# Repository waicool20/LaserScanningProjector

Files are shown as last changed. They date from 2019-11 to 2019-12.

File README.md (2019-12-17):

# Laser Scanning Projector

Use a scanning laser to draw images onto a surface!

## Project Structure

- `Hardware`: Contains PCB schematics and STM32CubeMX IOC file
- `Software`: Software for the MCU
- `Software-PC`: PC-side software for streaming USB data
- `Report`: Report for submission to course

# License

Hardware: Creative Commons Attribution-ShareAlike 4.0 International

Software: MIT

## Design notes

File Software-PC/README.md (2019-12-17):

# Laser Scanning Projector - PC Companion Software

Companion software for streaming image data to the Laser Scanning Projector.

## Getting Started

These instructions will set the project up and run the application on your 
local machine. Note that currently only the Linux platform is officially tested 
and supported.

### Prerequisites

- [CMake 3.10.0+](https://cmake.org/download/)
- Any C++17-supported compiler

### Compiling and Running

Run CMake in a separate directory.
```bash
cmake -G "CodeBlocks - Unix Makefiles" ..
cmake --build . --target all
```

The application will be named as `LaserScanningProject-PC`.

## Usage

```
LaserScanningProject-PC <image_file>
```

- `<image_file>`: Path to the image file to render

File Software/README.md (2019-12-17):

# Laser Scanning Projector

## Prerequisites

You will be needing the following to compile:

- [arm-none-eabi-gcc](https://developer.arm.com/open-source/gnu-toolchain/gnu-rm)
- [CMake](https://cmake.org/)
- [GNU Make](https://www.gnu.org/software/make/)
- [Python](https://www.python.org/)

## Usage

1. Clone this repository to your local system. 

```bash
git clone https://github.com/waicool20/LaserScanningProjector.git
```

2. Initialize all the submodule dependencies.

```bash
cd LaserScanningProjector
git submodule update --init --recursive
```

3. Build LibOpenCM3.

This step is required by RTLib to recognize which targets are supported by libopencm3. Subsequent builds can skip this 
step, as building RTLib will implicitly build libopencm3.

```bash
cd Software/libopencm3
make
cd ..
```
4. Try to build the application.

```bash
# Create a new folder to house all CMake-related files.
mkdir cmake-build && cd cmake-build

# Change the -G option according to your build system, might be different for example if you were using MinGW.
cmake -DCMAKE_BUILD_TYPE=Debug -DCMAKE_TOOLCHAIN_FILE=../cmake/arm-toolchain.cmake -G "CodeBlocks - Unix Makefiles" ..

# Finally run the make command to initate the build process. This will build everything into the "cmake-build" folder.
cmake --build . --target all
```

The resulting binaries (`LaserScanningProjector.bin` and `LaserScanningProjector.elf`) will be located in the same 
directory.

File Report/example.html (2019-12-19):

## ELEC 3300 Final Project

## Title: <Laser Scanning Projector>

## Group: 26

Members Name | Ching Hang MAK | Wai Paulo Valerio WANG
Members Email | chmakac@connect.ust.hk | wpvwang@connect.ust.hk

# Project Resources

## Project Summary

## Proposal Presentation Video (https://photos.app.goo.gl/xhKpi9jK36LHvkUt7)

## Project Interim Demo Video (https://photos.app.goo.gl/K36WhH9UAJNqvfp79)

## Project Final PowerPoint Presentation

## Working Function Demo (https://photos.app.goo.gl/PB6YHP3vdHEFazZNA)

## STM32CubeMX ioc file

## Software Source Code (Mirror: GitHub (https://github.com/waicool20/LaserScanningProjector/tree/master/Software))

## GitHub (Contains source code for everything) (https://github.com/waicool20/LaserScanningProjector/)

# Photos

For more photos please check the Timeline section in 'Project Final PowerPoint Presentation'

## Front View Photo



## Top View Photo

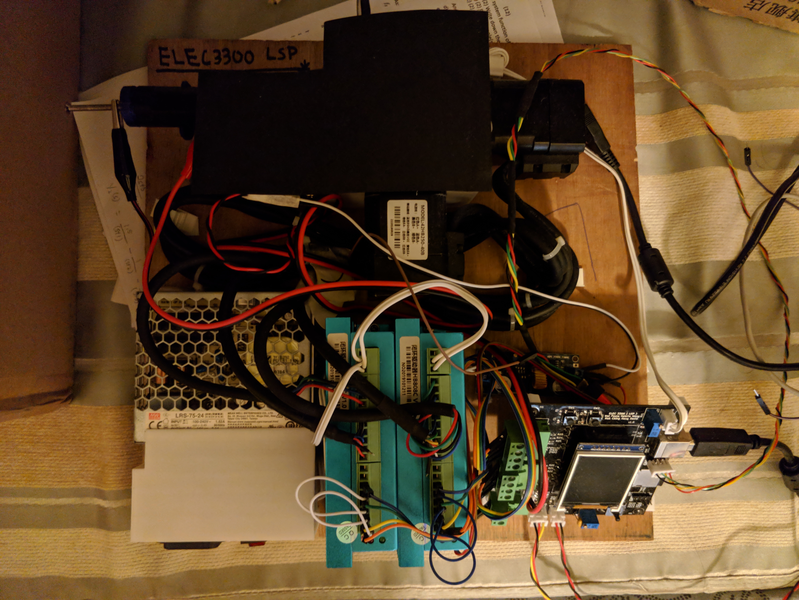
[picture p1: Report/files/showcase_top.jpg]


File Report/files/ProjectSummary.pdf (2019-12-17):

## ELEC 3300 Project Summary Sheet

This is a ONE Page Summary Sheet, Content more than 1 page will be deleted. All the fonts used in this Sheet should be in Times New Roman at 12 points

Group Number | 26
Project Title | Laser Scanning Projector
Name of Student 1 | Wai Paulo Valerio Wang
Name of Student 2 | Mak Ching Hang David

Please attach ONE photo of your project here

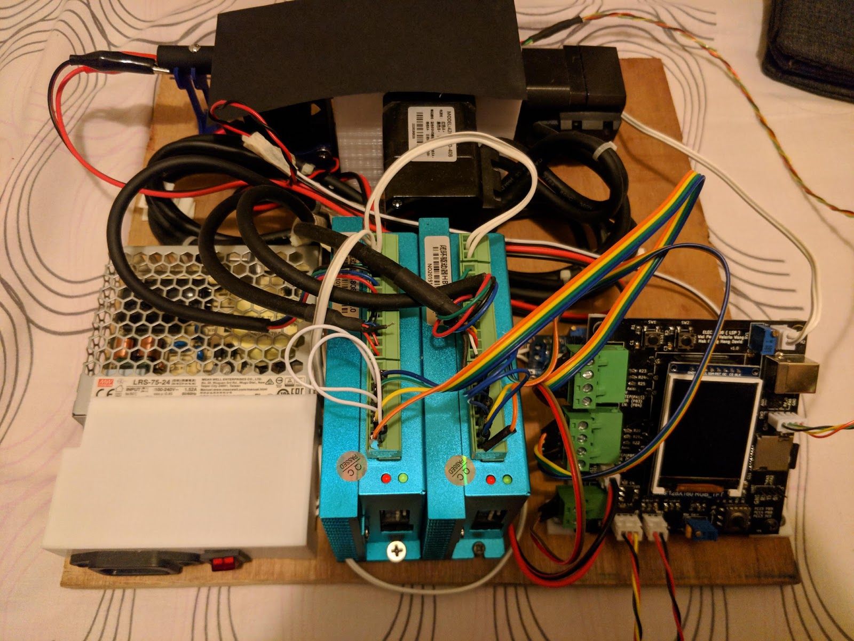
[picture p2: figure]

Please list the functions of your project in point form

- Draw image using laser, multiple data sources
- Data from memory
- Data from sd card
- Data from usb
- Data from uart
- Plot audio magnitude as y axis, audio source from mic
- Plot audio magnitude as xy axis, audio source from headphone jack
- LCD for mode selection
- Auto Homing

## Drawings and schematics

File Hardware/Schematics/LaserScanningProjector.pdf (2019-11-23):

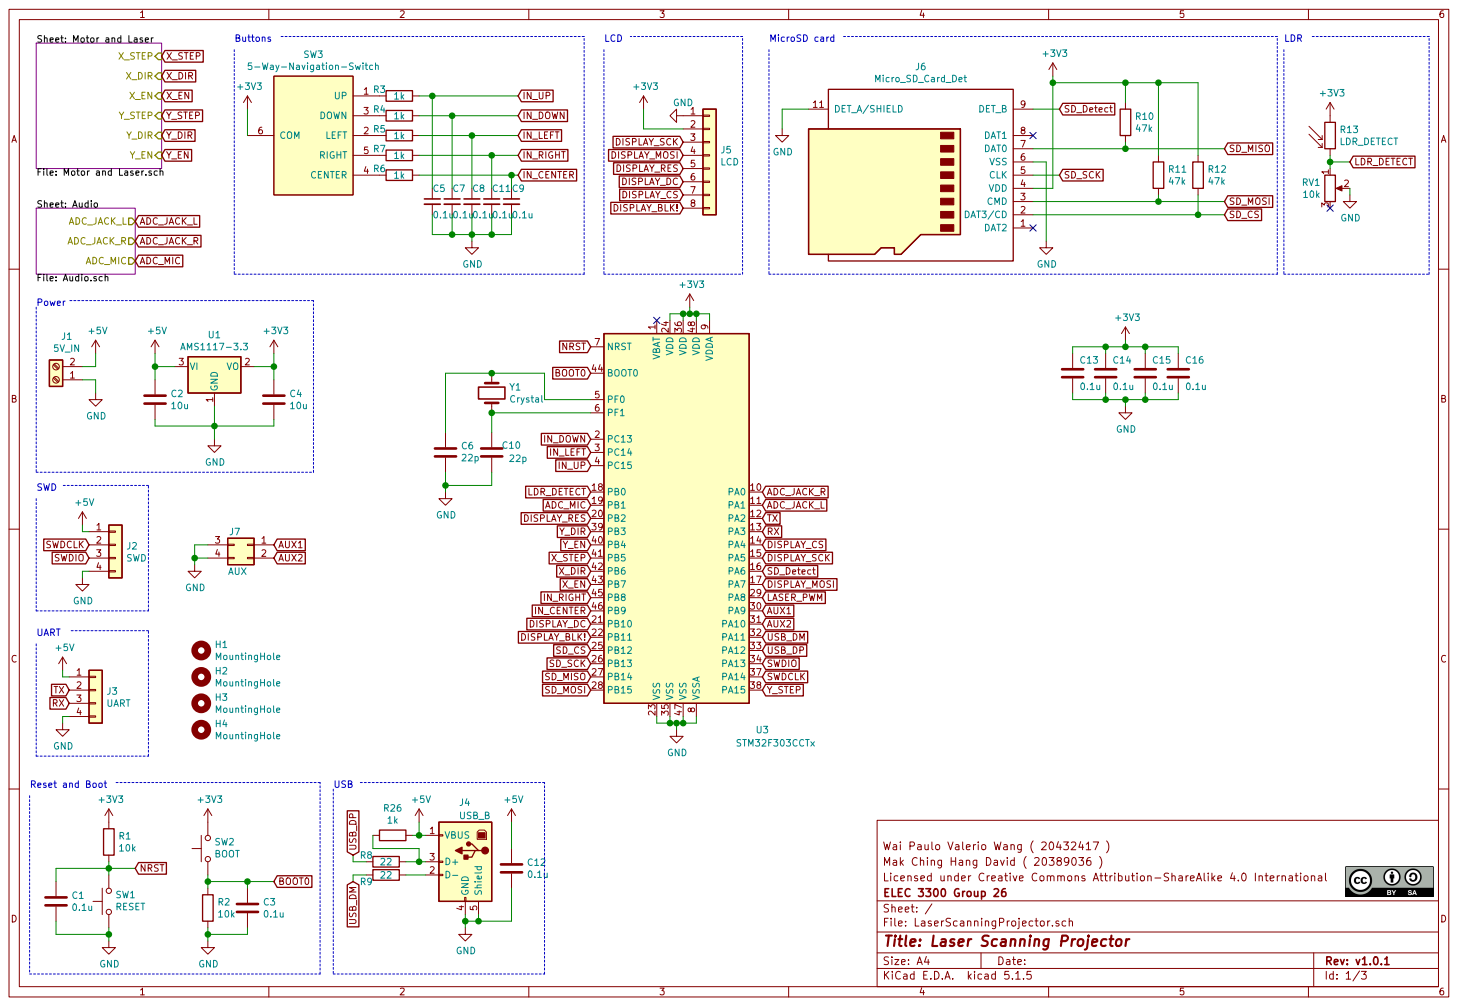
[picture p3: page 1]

Sheet: Motor and Laser File: Motor and Laser.sch X_STEP

Sheet: Audio File: Audio.sch ADC_JACK_L ADC_JACK_R

1 VDD 24 VDD 36 VDD 48 VDDA

9 VSS 23 VSS 35 VSS 47 VSSA

Wai Paulo Valerio Wang ( 20432417 )
Licensed under Creative Commons Attribution-ShareAlike 4.0 International Mak Ching Hang David ( 20389036 )

File: LaserScanningProjector.sch Sheet: / ELEC 3300 Group 26

Id: 1/3 Title: Laser Scanning Projector

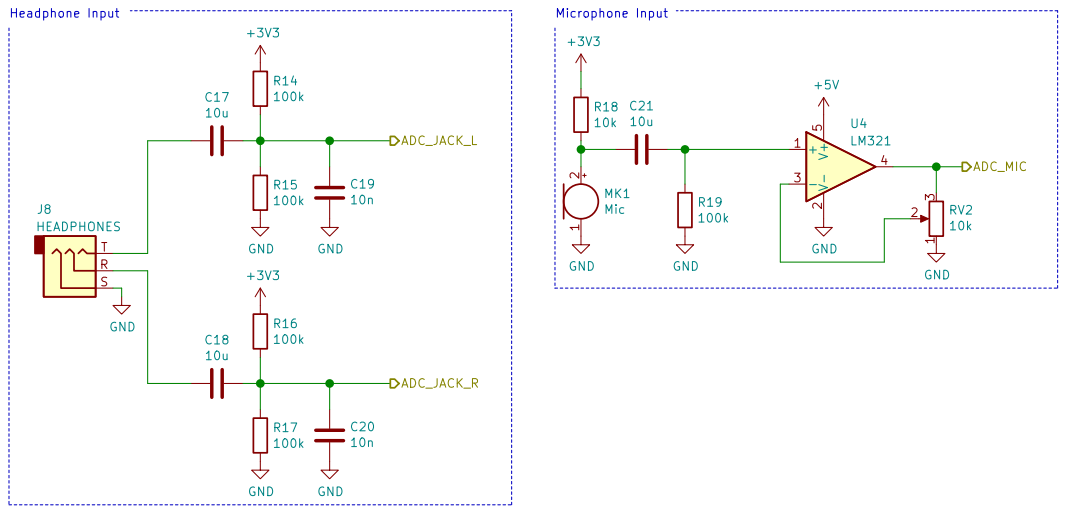
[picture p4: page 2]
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

Id: 2/3 Title: Laser Scanning Projector File: Audio.sch Sheet: /Audio/ ELEC 3300 Group 26

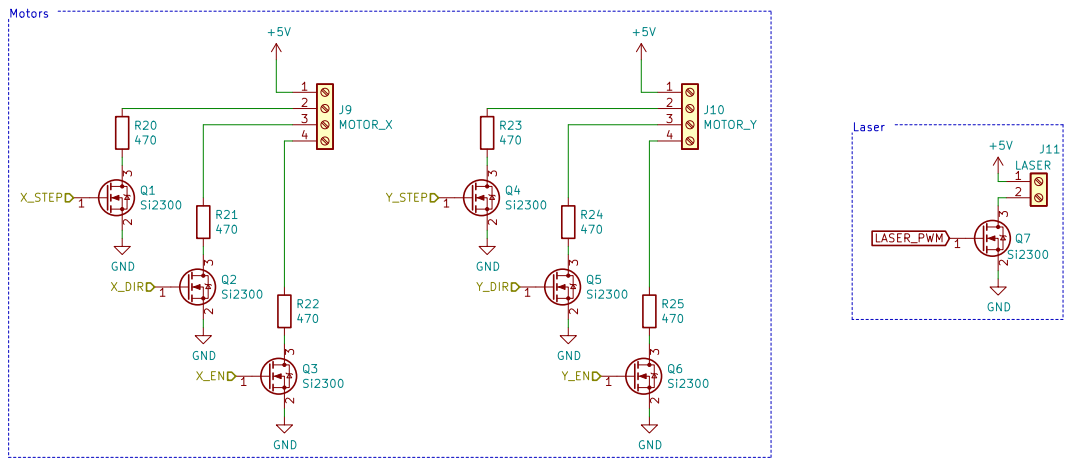
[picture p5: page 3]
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

Id: 3/3 Title: Laser Scanning Projector File: Motor and Laser.sch Sheet: /Motor and Laser/ ELEC 3300 Group 26

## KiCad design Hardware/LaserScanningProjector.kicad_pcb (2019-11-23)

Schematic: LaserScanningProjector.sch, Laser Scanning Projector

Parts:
C1, C3, C5, C7, C8, C9, C11, C12, C13, C14, C15, C16: 0.1u; C_0805_2012Metric_Pad1.15x1.40mm_HandSolder
C2, C4: 10u; C_0805_2012Metric_Pad1.15x1.40mm_HandSolder
C6, C10: 22p; C_0805_2012Metric_Pad1.15x1.40mm_HandSolder
H1, H2, H3, H4: MountingHole; MountingHole_3.2mm_M3_Pad
J1: 5V_IN; PhoenixContact_MSTBA_2,5_2-G-5,08_1x02_P5.08mm_Horizontal
J2: SWD; PinHeader_1x04_P2.54mm_Vertical
J3: UART; PinHeader_1x04_P2.54mm_Vertical
J4: USB_B
J5: LCD
J6: Micro_SD_Card_Det; Micro_SD
J7: AUX; PinHeader_2x02_P2.54mm_Vertical
R1, R2: 10k; R_0805_2012Metric_Pad1.15x1.40mm_HandSolder
R3, R4, R5, R6, R7, R26: 1k; R_0805_2012Metric_Pad1.15x1.40mm_HandSolder
R8, R9: 22; R_0805_2012Metric_Pad1.15x1.40mm_HandSolder
R10, R11, R12: 47k; R_0805_2012Metric_Pad1.15x1.40mm_HandSolder
R13: LDR_DETECT; JST_XH_B2B-XH-A_1x02_P2.50mm_Vertical
RV1: 10k; Potentiometer_Bourns_3296W_Vertical
SW1: RESET; SW_SPST_PTS645
SW2: BOOT; SW_SPST_PTS645
SW3: 5-Way-Navigation-Switch; 5-Way-Nagivation-Switch
U1: AMS1117-3.3; SOT-223-3_TabPin2
U3: STM32F303CCTx; LQFP-48_7x7mm_P0.5mm
Y1: Crystal; Crystal_HC49-4H_Vertical

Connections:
+3V3: C4.1, C13.1, C14.1, C15.1, C16.1, J5.2, J6.4 (VDD), R1.1, R10.1, R11.1, R12.1, R13.1, SW2.2, SW3.6, U1.2 (VO), U3.9 (VDDA), U3.24 (VDD), U3.36 (VDD), U3.48 (VDD); also elsewhere on the board
+5V: C2.1, C12.1, J1.2, J2.1, J3.1, J4.1 (VBUS), R26.1, U1.3 (VI); also elsewhere on the board
ADC_JACK_L: U3.11 (PA1); also elsewhere on the board
ADC_JACK_R: U3.10 (PA0); also elsewhere on the board
ADC_MIC: U3.19 (PB1); also elsewhere on the board
AUX1: J7.1, U3.30 (PA9)
AUX2: J7.2, U3.31 (PA10)
BOOT0: C3.1, R2.1, SW2.1, U3.44 (BOOT0)
DISPLAY_BLK!: J5.8, U3.22 (PB11)
DISPLAY_CS: J5.7, U3.14 (PA4)
DISPLAY_DC: J5.6, U3.21 (PB10)
DISPLAY_MOSI: J5.4, U3.17 (PA7)
DISPLAY_RES: J5.5, U3.20 (PB2)
DISPLAY_SCK: J5.3, U3.15 (PA5)
GND: C1.2, C2.2, C3.2, C4.2, C5.2, C6.1, C7.2, C8.2, C9.2, C10.1, C11.2, C12.2, C13.2, C14.2, C15.2, C16.2, J1.1, J2.4, J3.4, J4.4 (GND), J4.5 (Shield), J5.1, J6.6 (VSS), J6.11 (DET_A/SHIELD), J7.3, J7.4, R2.2, RV1.2, SW1.1, U1.1 (GND), U3.8 (VSSA), U3.23 (VSS), U3.35 (VSS), U3.47 (VSS); also elsewhere on the board
IN_CENTER: C9.1, R6.1, U3.46 (PB9)
IN_DOWN: C7.1, R4.1, U3.2 (PC13)
IN_LEFT: C8.1, R5.1, U3.3 (PC14)
IN_RIGHT: C11.1, R7.1, U3.45 (PB8)
IN_UP: C5.1, R3.1, U3.4 (PC15)
LASER_PWM: U3.29 (PA8); also elsewhere on the board
LDR_DETECT: R13.2, RV1.1, U3.18 (PB0)
NRST: C1.1, R1.2, SW1.2, U3.7 (NRST)
unnamed: C6.2, U3.5 (PF0), Y1.1
unnamed: C10.2, U3.6 (PF1), Y1.2
unnamed: J4.2 (D-), R9.1
unnamed: J4.3 (D+), R8.1, R26.2
unnamed: R3.2, SW3.1
unnamed: R4.2, SW3.3
unnamed: R5.2, SW3.2
unnamed: R6.2, SW3.4
unnamed: R7.2, SW3.5
RX: J3.3, U3.13 (PA3)
SD_CS: J6.2 (DAT3/CD), R12.2, U3.25 (PB12)
SD_Detect: J6.9 (DET_B), U3.16 (PA6)
SD_MISO: J6.7 (DAT0), R10.2, U3.27 (PB14)
SD_MOSI: J6.3 (CMD), R11.2, U3.28 (PB15)
SD_SCK: J6.5 (CLK), U3.26 (PB13)
SWDCLK: J2.2, U3.37 (PA14)
SWDIO: J2.3, U3.34 (PA13)
TX: J3.2, U3.12 (PA2)
USB_DM: R9.2, U3.32 (PA11)
USB_DP: R8.2, U3.33 (PA12)
X_DIR: U3.42 (PB6); also elsewhere on the board
X_EN: U3.43 (PB7); also elsewhere on the board
X_STEP: U3.41 (PB5); also elsewhere on the board
Y_DIR: U3.39 (PB3); also elsewhere on the board
Y_EN: U3.40 (PB4); also elsewhere on the board
Y_STEP: U3.38 (PA15); also elsewhere on the board

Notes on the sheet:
Reset and Boot
SWD
UART
USB
MicroSD card
LCD
Buttons
LDR
Power

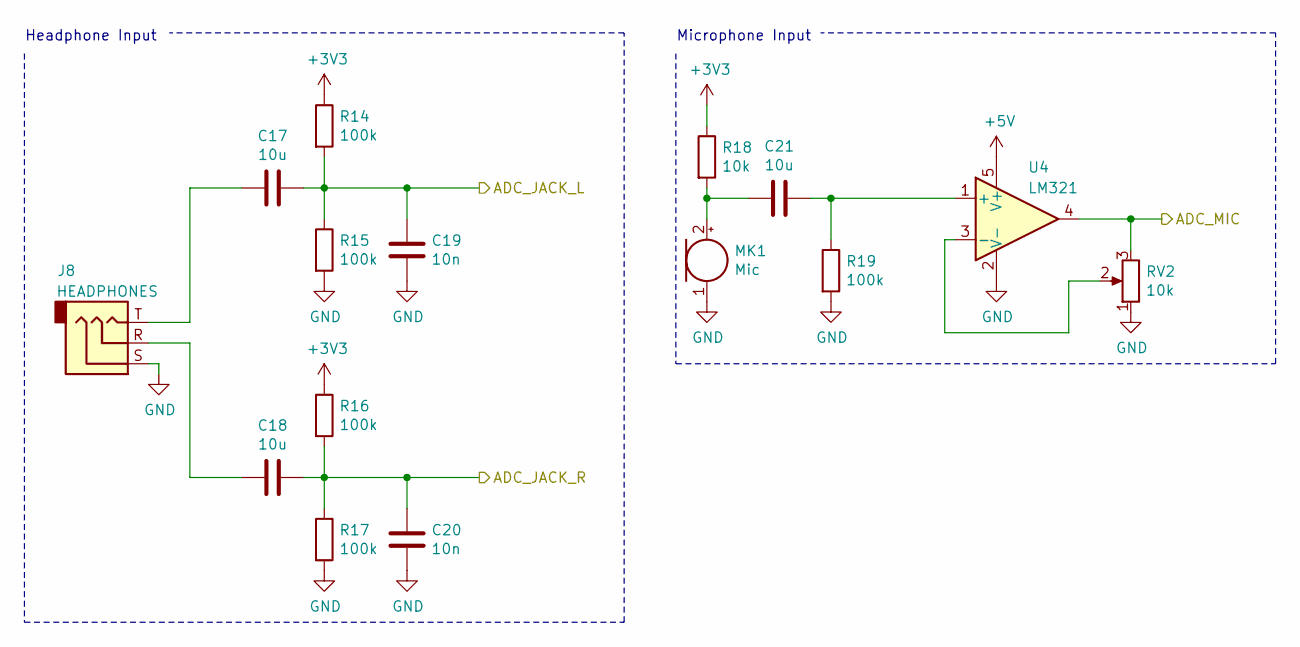
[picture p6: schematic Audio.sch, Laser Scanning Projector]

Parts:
C17, C18, C21: 10u; C_0805_2012Metric_Pad1.15x1.40mm_HandSolder
C19, C20: 10n; C_0805_2012Metric_Pad1.15x1.40mm_HandSolder
J8: HEADPHONES; JST_XH_B3B-XH-A_1x03_P2.50mm_Vertical_RST_AUDIO
MK1: Mic; JST_XH_B2B-XH-A_1x02_P2.50mm_Vertical
R14, R15, R16, R17, R19: 100k; R_0805_2012Metric_Pad1.15x1.40mm_HandSolder
R18: 10k; R_0805_2012Metric_Pad1.15x1.40mm_HandSolder
RV2: 10k; Potentiometer_Bourns_3296W_Vertical
U4: LM321; SOT-23-5

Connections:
+3V3: R14.1, R16.1, R18.1; also elsewhere on the board
+5V: U4.5 (V+); also elsewhere on the board
ADC_JACK_L: C17.1, C19.2, R14.2, R15.1; also elsewhere on the board
ADC_JACK_R: C18.1, C20.2, R16.2, R17.1; also elsewhere on the board
ADC_MIC: RV2.3, U4.4; also elsewhere on the board
GND: C19.1, C20.1, J8.S, MK1.1 (-), R15.2, R17.2, R19.2, RV2.1, U4.2 (V-); also elsewhere on the board
unnamed: C17.2, J8.T
unnamed: C18.2, J8.R
unnamed: C21.1, R19.1, U4.1 (+)
unnamed: C21.2, MK1.2 (+), R18.2
unnamed: RV2.2, U4.3 (-)

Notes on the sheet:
Headphone Input
Microphone Input

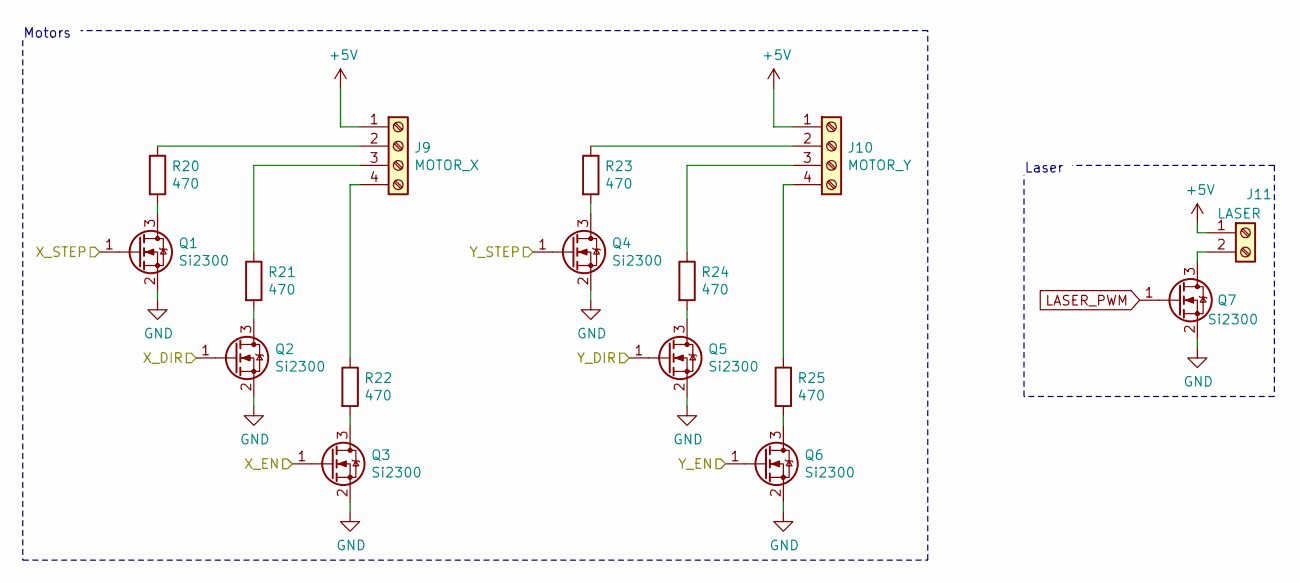
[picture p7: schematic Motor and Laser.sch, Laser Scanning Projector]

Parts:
J9: MOTOR_X; PhoenixContact_MSTBA_2,5_4-G-5,08_1x04_P5.08mm_Horizontal
J10: MOTOR_Y; PhoenixContact_MSTBA_2,5_4-G-5,08_1x04_P5.08mm_Horizontal
J11: LASER; JST_XH_B2B-XH-A_1x02_P2.50mm_Vertical
Q1, Q2, Q3, Q4, Q5, Q6, Q7: Si2300; SOT-23
R20, R21, R22, R23, R24, R25: 470; R_0805_2012Metric_Pad1.15x1.40mm_HandSolder

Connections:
+5V: J9.1, J10.1, J11.1; also elsewhere on the board
GND: Q1.2 (S), Q2.2 (S), Q3.2 (S), Q4.2 (S), Q5.2 (S), Q6.2 (S), Q7.2 (S); also elsewhere on the board
LASER_PWM: Q7.1 (G); also elsewhere on the board
unnamed: J9.2, R20.1
unnamed: J9.3, R21.1
unnamed: J9.4, R22.1
unnamed: J10.2, R23.1
unnamed: J10.3, R24.1
unnamed: J10.4, R25.1
unnamed: J11.2, Q7.3 (D)
unnamed: Q1.3 (D), R20.2
unnamed: Q2.3 (D), R21.2
unnamed: Q3.3 (D), R22.2
unnamed: Q4.3 (D), R23.2
unnamed: Q5.3 (D), R24.2
unnamed: Q6.3 (D), R25.2
X_DIR: Q2.1 (G); also elsewhere on the board
X_EN: Q3.1 (G); also elsewhere on the board
X_STEP: Q1.1 (G); also elsewhere on the board
Y_DIR: Q5.1 (G); also elsewhere on the board
Y_EN: Q6.1 (G); also elsewhere on the board
Y_STEP: Q4.1 (G); also elsewhere on the board

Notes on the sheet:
Motors
Laser

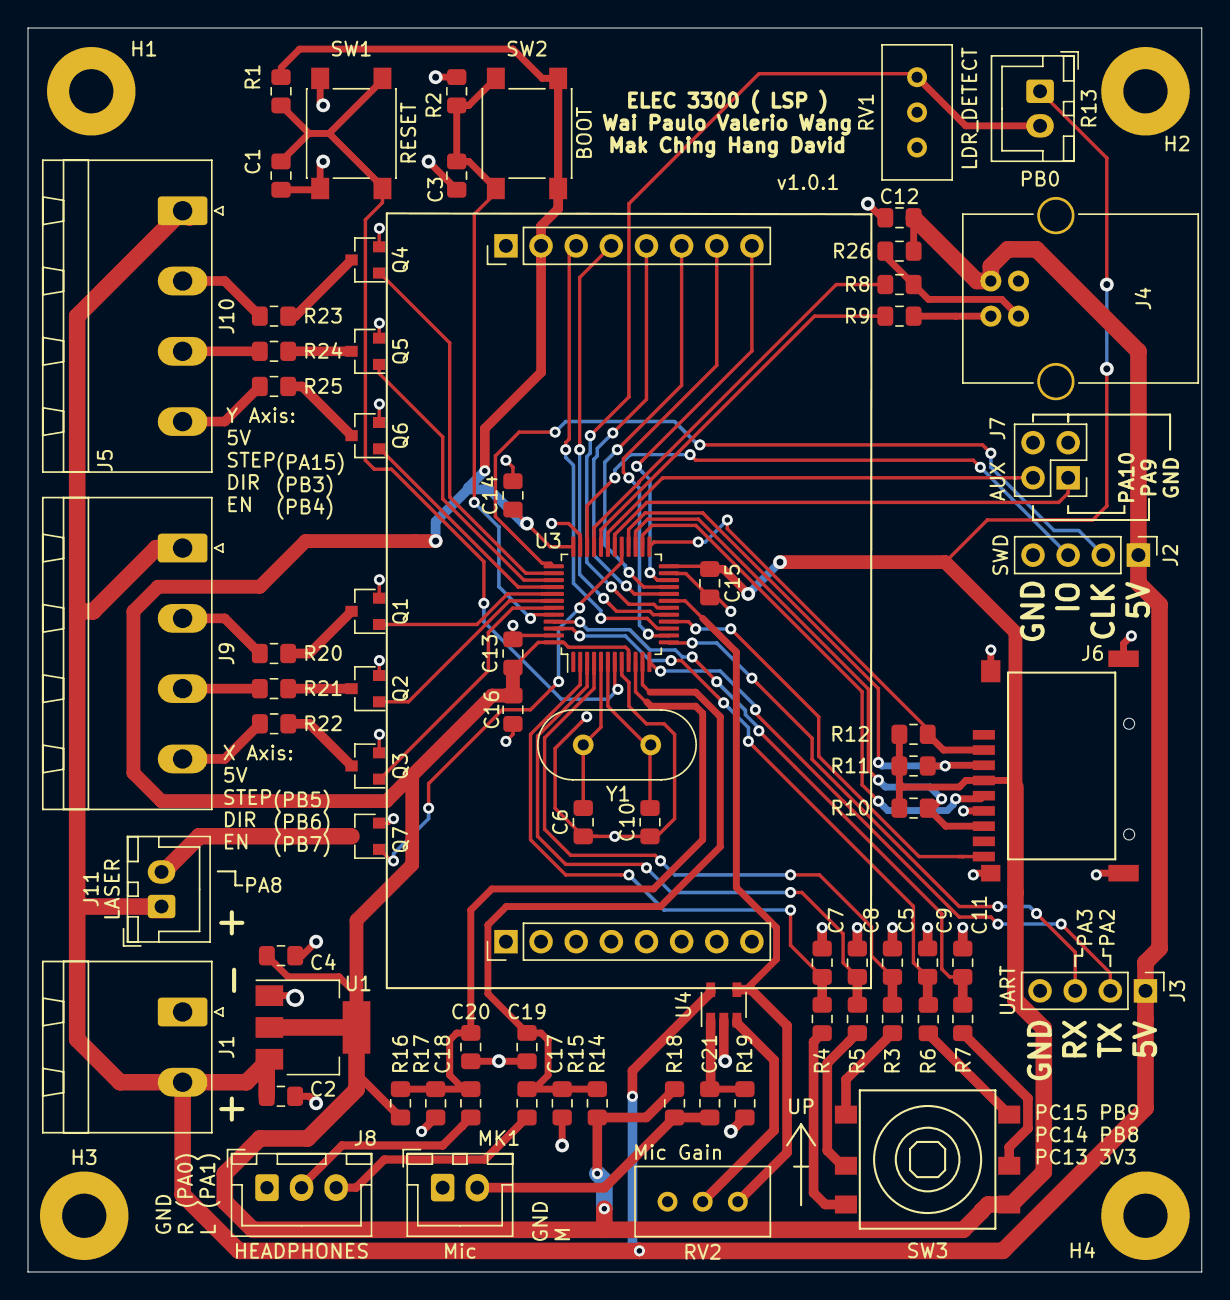
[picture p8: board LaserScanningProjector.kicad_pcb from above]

Board: 2 copper layers, 84.8 x 89.9 mm, 79 parts (0 on the bottom side), 67 nets.

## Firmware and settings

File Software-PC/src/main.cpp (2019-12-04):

#include <array>
#include <numeric>
#include <string_view>
#include <thread>
#include <vector>

#include <fmt/format.h>
#include <libusb-1.0/libusb.h>
#include <opencv2/opencv.hpp>

using namespace std::literals;

namespace {
constexpr std::uint16_t vid = 0x0483;
constexpr std::uint16_t pid = 0x5740;

constexpr auto w = 320;
constexpr auto h = 240;

void libusb_check_error(int rc, const char* func_name) {
  if (rc < 0) {
    std::string e_what = "Error initializing libusb: ";
    e_what += libusb_error_name(rc);
    fmt::print(stderr, "{}: {}", func_name, e_what);
    throw std::runtime_error(e_what);
  }
}

void libusb_cdc_claim_interface(libusb_device_handle* const device_handle) {
  for (int if_num = 0; if_num < 2; ++if_num) {
    if (libusb_kernel_driver_active(device_handle, if_num) != 0) {
      libusb_detach_kernel_driver(device_handle, if_num);
    }
    libusb_check_error(libusb_claim_interface(device_handle, if_num), __func__);
  }
}

void libusb_cdc_init_line_state(libusb_device_handle* const device_handle) {
  libusb_check_error(libusb_control_transfer(device_handle, 0x21, 0x22, 0x01 | 0x02, 0, nullptr, 0, 0), __func__);
}

void libusb_cdc_init_line_encoding(libusb_device_handle* const device_handle) {
  std::array<unsigned char, 8> encoding = {0x80, 0x25, 0x00, 0x00, 0x00, 0x00, 0x08, 0x00};
  libusb_check_error(libusb_control_transfer(device_handle, 0x21, 0x20, 0, 0, encoding.data(), encoding.size(), 0), __func__);
}

void libusb_write(libusb_device_handle* const device_handle, std::vector<unsigned char>& data) {
  int actual_length;
  if (int rc = libusb_bulk_transfer(device_handle, 0x01, data.data(), data.size(), &actual_length, 0); rc < 0) {
    fmt::print(stderr, "Error while sending data\n");
  } else if (data.size() != actual_length) {
    fmt::print(stderr, "Incomplete packet sent!\n");
  }
}

void libusb_read(libusb_device_handle* const device_handle, std::vector<unsigned char>& buffer) {
  int actual_length;
  if (int rc = libusb_bulk_transfer(device_handle, 0x82, buffer.data(), buffer.size(), &actual_length, 1000); rc < 0) {
    if (rc == LIBUSB_ERROR_TIMEOUT) {
      fmt::print(stderr, "Request timed out with {} bytes sent\n", actual_length);
    } else {
      fmt::print("Error while waiting for data\n");
    }

    buffer.resize(0);
  } else {
    buffer.resize(actual_length);
  }
}

struct packet {
  std::uint16_t x;
  std::uint16_t y;
  bool state;
};

constexpr std::array<packet, 4> tuples = {{
                                              {0, 0, true},
                                              {127, 0, true},
                                              {127, 71, true},
                                              {0, 71, true}
                                          }};

}  // namespace

void resize_keep_ratio(cv::Mat& src, cv::Mat& dest, const cv::Size& target) {
  const auto y_scale = double(target.height) / src.rows;
  const auto x_scale = double(target.width) / src.cols;

  const auto scale = std::min(x_scale, y_scale);
  cv::resize(src, dest, cv::Size(src.cols * scale, src.rows * scale), scale, scale);
}

int main(int argc, char* argv[]) {
  std::vector tuples(::tuples.begin(), ::tuples.end());
  if (argc == 2) {
    tuples.clear();
    cv::Mat src = cv::imread(argv[1], cv::IMREAD_COLOR);
    if (src.empty()) {
      fmt::print("Could not open or find the image!\n");
      fmt::print("Usage: {} <Input image>\n", argv[0]);
      return -1;
    }

    resize_keep_ratio(src, src, cv::Size(w, h));

    cv::Mat src_gray;
    cvtColor(src, src_gray, cv::COLOR_BGR2GRAY);

    constexpr auto dist_thresh = 200;
    constexpr auto lines_thresh = 200;
    constexpr auto lowThreshold = 0;
    constexpr auto max_lowThreshold = 100;

    cv::Mat detected_edges;
    std::vector<std::vector<cv::Point>> contours;
    std::vector<cv::Vec4i> hierarchy;
    std::pair<std::size_t, std::size_t> bounds = {lowThreshold, max_lowThreshold};
    double accumulator = 0.0;
    while (true) {
      const auto threshold = double(bounds.first + bounds.second) / 2;
      contours.clear();
      hierarchy.clear();

      blur(src_gray, detected_edges, cv::Size(3, 3));
      Canny(detected_edges, detected_edges, threshold, threshold * 3, 3);
      findContours(detected_edges, contours, hierarchy, cv::RETR_TREE, cv::CHAIN_APPROX_SIMPLE);

      if (std::fabs(bounds.second - bounds.first) <= 1.0f) {
        break;
      } else if (threshold == lowThreshold || threshold + 1 == max_lowThreshold) {
        break;
      }

      if (contours.size() > lines_thresh) {
        bounds.first = (bounds.first + bounds.second) / 2;
      }

      std::vector<double> distances(contours.size());
      std::transform(contours.begin(), contours.end(), distances.begin(), [](const std::vector<cv::Point>& vp) {
        const double x = vp.back().x - vp.front().x;
        const double y = vp.back().y - vp.back().y;
        return std::sqrt(x * x + y * y);
      });
      accumulator = std::accumulate(distances.begin(), distances.end(), 0.0);
      if (accumulator < dist_thresh) {
        bounds.second = double(bounds.first + bounds.second) / 2;
      } else if (accumulator > dist_thresh) {
        bounds.first = double(bounds.first + bounds.second) / 2;
      } else {
        break;
      }
    }

    std::vector<double> distances(contours.size());
    std::transform(contours.begin(), contours.end(), distances.begin(), [](const std::vector<cv::Point>& vp) {
      const double x = vp.back().x - vp.front().x;
      const double y = vp.back().y - vp.back().y;
      return std::sqrt(x * x + y * y);
    });
    accumulator = std::accumulate(distances.begin(), distances.end(), 0.0);
    fmt::print("Displaying Edges: {}, Distance: {}\n", contours.size(), accumulator);
    for (const auto& line : contours) {
      const auto last = --line.end();

      for (auto it = line.begin(); it != line.end(); ++it) {
        const bool state = it != last;
        const packet p = {
            std::uint16_t(it->x),
            std::uint16_t(it->y),
            state
        };
        tuples.emplace_back(p);
      }
    }
  }

  libusb_check_error(libusb_init(nullptr), __func__);

  libusb_set_option(nullptr, LIBUSB_OPTION_LOG_LEVEL, 3);

  libusb_device_handle* device_handle = nullptr;
  while (device_handle == nullptr) {
    if ((device_handle = libusb_open_device_with_vid_pid(nullptr, vid, pid)) != nullptr) {
      break;
    }

    fmt::print(stderr, "Error finding USB device! Retrying in 5 seconds...\n");
    std::this_thread::sleep_for(5s);
  }

  libusb_cdc_claim_interface(device_handle);
  libusb_cdc_init_line_state(device_handle);
  libusb_cdc_init_line_encoding(device_handle);

  std::vector<unsigned char> out_data(8);
  std::vector<unsigned char> in_data(1024);

  auto it = tuples.begin();
  while (true) {
    out_data.resize(8);
    in_data.resize(1024);

    out_data[0] = static_cast<unsigned char>((it->x >> 8) & 0xFF);
    out_data[1] = static_cast<unsigned char>((it->x >> 0) & 0xFF);
    out_data[2] = static_cast<unsigned char>((it->y >> 8) & 0xFF);
    out_data[3] = static_cast<unsigned char>((it->y >> 0) & 0xFF);
    out_data[4] = static_cast<unsigned char>(it->state);

    libusb_write(device_handle, out_data);
    libusb_read(device_handle, in_data);

    if (in_data.front() != 0) {
      if (in_data.front() != 1) {
        fmt::print(stderr, "Expected 0, got {}\n", in_data.front());
      }
    } else {
      ++it;
      if (it == tuples.end()) {
        it = tuples.begin();
      }
    }

    std::this_thread::sleep_for(std::chrono::milliseconds(1));
  }
}

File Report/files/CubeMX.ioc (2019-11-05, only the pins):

Mcu.UserName=STM32F303CCTx
PA0.GPIO_Label=ADC_JACK_R
PA0.Signal=ADC1_IN1
PA1.GPIO_Label=ADC_JACK_L
PA1.Signal=ADC1_IN2
PA10.GPIO_Label=AUX2
PA10.Signal=GPIO_Output
PA11.Signal=USB_DM
PA12.Signal=USB_DP
PA13.Signal=SYS_JTMS-SWDIO
PA14.Signal=SYS_JTCK-SWCLK
PA15.GPIO_Label=Y_STEP
PA15.Signal=GPIO_Output
PA2.Signal=USART2_TX
PA3.Signal=USART2_RX
PA4.GPIO_Label=DISPLAY_CS
PA4.Signal=SPI1_NSS
PA5.GPIO_Label=DISPLAY_SCK
PA5.Signal=SPI1_SCK
PA6.GPIO_Label=SD_DETECT
PA6.Signal=GPIO_Input
PA7.GPIO_Label=DISPLAY_MOSI
PA7.Signal=SPI1_MOSI
PA8.GPIO_Label=LASER_PWM
PA8.Signal=S_TIM1_CH1
PA9.GPIO_Label=AUX1
PA9.Signal=GPIO_Output
PB0.GPIO_Label=LDR_DETECT
PB0.Signal=GPIO_Input
PB1.GPIO_Label=ADC_MIC
PB1.Signal=ADC3_IN1
PB10.GPIO_Label=DISPLAY_DC
PB10.Signal=GPIO_Output
PB11.GPIO_Label=DISPLAY_BLK\!
PB11.Signal=GPIO_Output
PB12.GPIO_Label=SD_CS
PB12.Signal=SPI2_NSS
PB13.GPIO_Label=SD_SCK
PB13.Signal=SPI2_SCK
PB14.GPIO_Label=SD_MISO
PB14.Signal=SPI2_MISO
PB15.GPIO_Label=SD_MOSI
PB15.Signal=SPI2_MOSI
PB2.GPIO_Label=DISPLAY_RES
PB2.Signal=GPIO_Output
PB3.GPIO_Label=Y_DIR
PB3.Signal=GPIO_Output
PB4.GPIO_Label=Y_EN
PB4.Signal=GPIO_Output
PB5.GPIO_Label=X_STEP
PB5.Signal=S_TIM3_CH2
PB6.GPIO_Label=X_DIR
PB6.Signal=GPIO_Output
PB7.GPIO_Label=X_EN
PB7.Signal=GPIO_Output
PB8.GPIO_Label=IN_RIGHT
PB8.Signal=GPIO_Input
PB9.GPIO_Label=IN_CENTER
PB9.Signal=GPIO_Input
PC13.GPIO_Label=IN_DOWN
PC13.Signal=GPIO_Input
PC14-OSC32_IN.GPIO_Label=IN_LEFT
PC14-OSC32_IN.Signal=GPIO_Input
PC15-OSC32_OUT.GPIO_Label=IN_UP
PC15-OSC32_OUT.Signal=GPIO_Input
PF0-OSC_IN.Signal=RCC_OSC_IN
PF1-OSC_OUT.Signal=RCC_OSC_OUT

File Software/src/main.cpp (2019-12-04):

#include <cstdint>

#include <libopencm3/stm32/gpio.h>
#include <libopencm3/stm32/rcc.h>

#include "main.h"
#include "drivers/laser.h"
#include "drivers/laser_canvas.h"
#include "drivers/nav5.h"
#include "drivers/stepper_motor.h"
#include "drivers/st7735s.h"
#include "lib/rcc.h"
#include "lib/systick.h"
#include "lib/usb_cdcacm.h"
#include "lib/ui.h"
#include "views/view_init.h"
#include "views/view_main.h"
#include "drivers/mic.h"
#include "drivers/headphones.h"
#include "images/smiley.h"

using namespace std::literals;

namespace {
constexpr uint32_t default_w = 128;
constexpr uint32_t default_h = 72;
}

namespace {
constexpr std::array<laser_canvas::tuple, 4> tuples = {{
                                                           {0, 0, true},
                                                           {127, 0, true},
                                                           {127, 71, true},
                                                           {0, 71, true}
                                                       }};
}  // namespace

render rendering = render::NONE;

int main() {
  rcc::clock_setup_pll(rcc_hse8mhz_configs[RCC_CLOCK_HSE8_72MHZ]);
  systick::init();

  rcc_periph_clock_enable(RCC_GPIOA);
  rcc_periph_clock_enable(RCC_GPIOB);
  rcc_periph_clock_enable(RCC_GPIOC);

  laser laser{};
  stepper_motor xM{gpio(GPIOB, GPIO7), gpio(GPIOB, GPIO6), gpio(GPIOB, GPIO5)};
  stepper_motor yM{gpio(GPIOB, GPIO4), gpio(GPIOB, GPIO3), gpio(GPIOA, GPIO15)};
  gpio ldr = gpio(GPIOB, GPIO0);
  laser_canvas canvas{25600, default_w, default_h, laser, xM, yM, ldr};

  st7735s lcd{0, 0, 128, 160, st7735s::COLOR_MODE_18_BITS};
  nav5 nav5{
      gpio(GPIOC, GPIO15),
      gpio(GPIOC, GPIO13),
      gpio(GPIOC, GPIO14),
      gpio(GPIOB, GPIO8),
      gpio(GPIOB, GPIO9)
  };

  std::uint64_t last_usb_cmd_issue = 0;

  ui::init(&lcd, &nav5);
  view_init::show(true);

  mic mic{};
  headphones headphones{};
  while (true) {
    switch (rendering) {
      case render::BASIC_RECT:
        canvas.resize(default_w, default_h);
        canvas.highlight_canvas_area();
        break;
      case render::BASIC_BITMAP:
        canvas.resize(default_w, default_h);
        canvas.draw_frame(&smiley_map[0]);
        break;
      case render::BASIC_TUPLE:
        canvas.resize(default_w, default_h);
        canvas.draw_tuples(tuples.data(), tuples.size());
        break;
      case render::DEBUG_HOME_LASER:
        canvas.home();
        rendering = render::NONE;
        break;
      case render::INIT_HOME_LASER:
        canvas.home();
        rendering = render::NONE;
        view_init::show(false);
        view_main::show(true);
        break;
      case render::AUDIO_MIC:
        mic.enable();
        canvas.resize(512, 512);
        canvas.draw_magnitude_y(mic.get_latest_value());
        break;
      case render::AUDIO_HEADPHONES:
        headphones.enable();
        canvas.resize(512, 512);
        canvas.draw_magnitude_y(headphones.channel_average());
        break;
      case render::AUDIO_HEADPHONES_XY:
        headphones.enable();
        canvas.resize(512, 512);
        canvas.draw_magnitude_xy(headphones.channel_x(), headphones.channel_y());
        break;
      case render::USB:
        canvas.resize(320, 240);
        if (usb_cdcacm::instance().tuple_present()) {
          last_usb_cmd_issue = systick::ms();
          const auto t = usb_cdcacm::instance().tuple_pop();
          canvas.draw_tuples(&t, 1);
        } else if (last_usb_cmd_issue - systick::ms() > 1000) {
          laser.disable();
        }
        break;
      case render::DEBUG_MANUAL:
        laser.enable();
        if (nav5.read_left()) {
          canvas.goto_xy(canvas.get_current_x() - 1, canvas.get_current_y(), false);
        } else if (nav5.read_right()) {
          canvas.goto_xy(canvas.get_current_x() + 1, canvas.get_current_y(), false);
        } else if (nav5.read_up()) {
          canvas.goto_xy(canvas.get_current_x(), canvas.get_current_y() - 1, false);
        } else if (nav5.read_down()) {
          canvas.goto_xy(canvas.get_current_x(), canvas.get_current_y() + 1, false);
        }
        break;
      case render::NONE:
      default:
        mic.disable();
        headphones.disable();
        canvas.clear();
        break;
    }
  }
}

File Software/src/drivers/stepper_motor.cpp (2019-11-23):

#include "stepper_motor.h"

#include "lib/systick.h"

stepper_motor::stepper_motor(gpio en, gpio dir, gpio step) :
    _en_(en), _dir_(dir), _step_(step) {
  _en_.setup(GPIO_MODE_OUTPUT, GPIO_PUPD_NONE);
  _dir_.setup(GPIO_MODE_OUTPUT, GPIO_PUPD_NONE);
  _step_.setup(GPIO_MODE_OUTPUT, GPIO_PUPD_NONE);

  _en_.output_opts(GPIO_OTYPE_PP, GPIO_OSPEED_50MHZ);
  _dir_.output_opts(GPIO_OTYPE_PP, GPIO_OSPEED_50MHZ);
  _step_.output_opts(GPIO_OTYPE_PP, GPIO_OSPEED_50MHZ);
}

void stepper_motor::set_enable(bool en) {
  _en_.state(!en);
  systick::sleep_us(5);
}

void stepper_motor::toggle_enable() {
  _en_.toggle();
  systick::sleep_us(5);
}

void stepper_motor::set_dir(direction dir) {
  _dir_.state(dir == direction::cw);
  systick::sleep_us(2);
}

void stepper_motor::toggle_dir() {
  _dir_.toggle();
  systick::sleep_us(2);
}

void stepper_motor::do_steps(std::uint32_t steps) {
  for (std::uint32_t i = 0; i < steps; i++) {
    _step_.state(true);
    systick::sleep_us(2);
    _step_.state(false);
    systick::sleep_us(2);
  }
}

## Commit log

2019-10-27 Adding production documents
    [LaserScanningProjector-B_Cu.gbl, LaserScanningProjector-B_Mask.gbs, LaserScanningProjector-B_Paste.gbp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]
2019-10-27 Update schematic metadata
    [Audio.sch, LaserScanningProjector.sch, Motor and Laser.sch]
2019-10-28 Minor changes to hardware
    - Changed laser power supply from 3v3 to 5v
    - 5v for more flexibility in laser diode selection
    - Bumped revision number to v1.0
    - Added version number to PCB
    [Audio.sch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]
2019-11-01 Add driver for motors
2019-11-02 Migrate to new stepper motor driver
    Finished implementing do_steps()
2019-11-03 Fix typo in silkscreen; Display BL -> PB11
    [LaserScanningProjector.kicad_pcb]
2019-11-05 Initial working implementation of lcd driver
2019-11-05 Add docs to lcd driver
2019-11-05 Swap center and right pins on 5 dir nav switch
    [LaserScanningProjector-B_Cu.gbl, LaserScanningProjector-B_Mask.gbs, LaserScanningProjector-B_Paste.gbp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]
2019-11-07 Implement laser driver
2019-11-07 Fix inverted brightness percent
    [laser.cpp]
2019-11-11 Implement laser_canvas; Implement laser homing;
2019-11-11 Always step x motor when detected by ldr
    Step the x off the ldr so it doesnt immediately trigger the check in next stage
2019-11-11 Set origin after homing
2019-11-11 Rename laser_canvas members
2019-11-11 Add getters for some laser_canvas properties
2019-11-11 Implement goto_xy for laser_canvas
2019-11-16 Change starting position of laser canvas
    Move the laser slightly out of the ldr way then go to center
2019-11-16 Do not initialize laser canvas during object construction
    Causes a long delay before the LCD actually works.
2019-11-16 Implement ui driver
2019-11-16 Implement 5 way nav switch driver
2019-11-16 Pass new state to pin external interrupt callbacks
2019-11-16 Implement ui input driver
2019-11-16 Fix left, right buttons not working
2019-11-16 Save pointers to display and input device in ui instance
2019-11-16 Add ui button input example code to main
2019-11-19 Fix LVGL target_include_directories path
    LVGL has an odd directory structure, with both the root and src
    containing headers. We fix this by adding both paths to
    target_include_directories.
    [main.cpp]
2019-11-23 Add pull-up resistor to usb dp
    [Audio.sch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]
2019-11-24 Push ui task handler to timer
2019-11-24 Temporarily disable laser_canvas frame check
2019-11-24 Add handle constructor to button
2019-11-24 Move ui timer init to end of init routine
2019-11-24 Add clear function to laser_canvas
2019-11-27 Set ui interrupt to lower priority
2019-11-30 Add option to skip homing
2019-11-30 Various changes
    - Poll USB using timer
    - Use staggered rendering to reduce artifacting
2019-11-30 Fix mic value equation
    [mic.cpp]
2019-12-04 [software] Add manual mode and fix infinite loop in PC software
    [main.cpp]
2019-12-04 [software] usb: Fix image cutoff issue
    It turns out that it is because when doubling the resolution, I forgot to bump the packet format to uint16_t.
    [main.cpp]
2019-12-04 Fix issue where transition from USB to other modes causes unsigned underflow
    [laser_canvas.cpp]
